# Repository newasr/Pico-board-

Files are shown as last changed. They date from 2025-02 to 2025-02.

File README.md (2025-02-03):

# Pico Board Replica

## Overview
This project is a replica of the Raspberry Pi Pico board, designed from scratch as a learning and practice exercise.

## Features
- Based on the RP2040 microcontroller
- Same form factor and pinout as the original Raspberry Pi Pico
- Designed using Kicad
- Fully open-source hardware

## Design Files
- **Schematics:**  
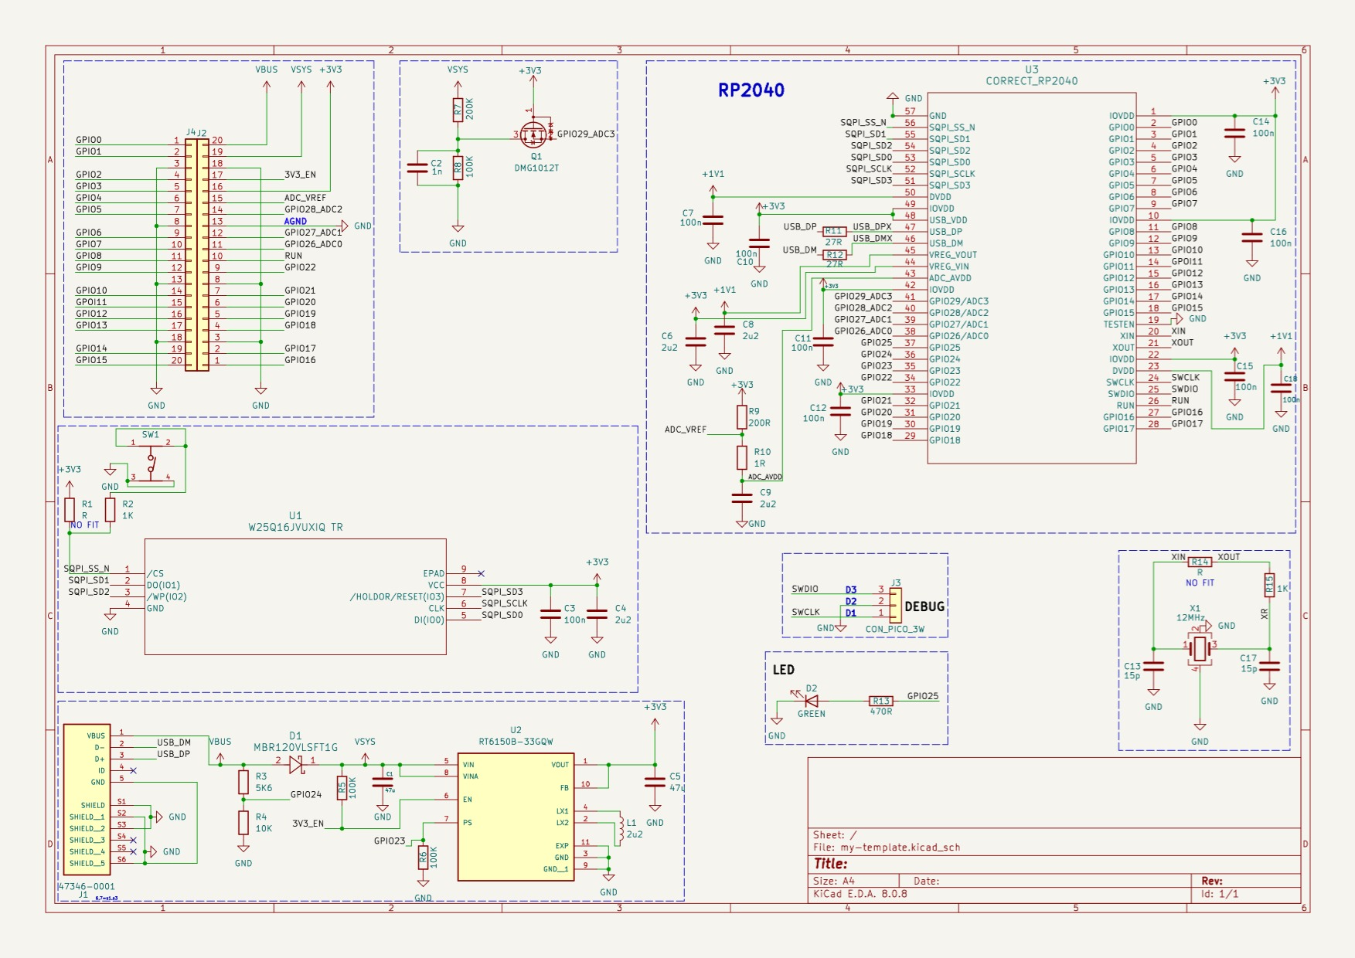
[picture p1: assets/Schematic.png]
Schematic
  
- **Final Product (3D View):**  
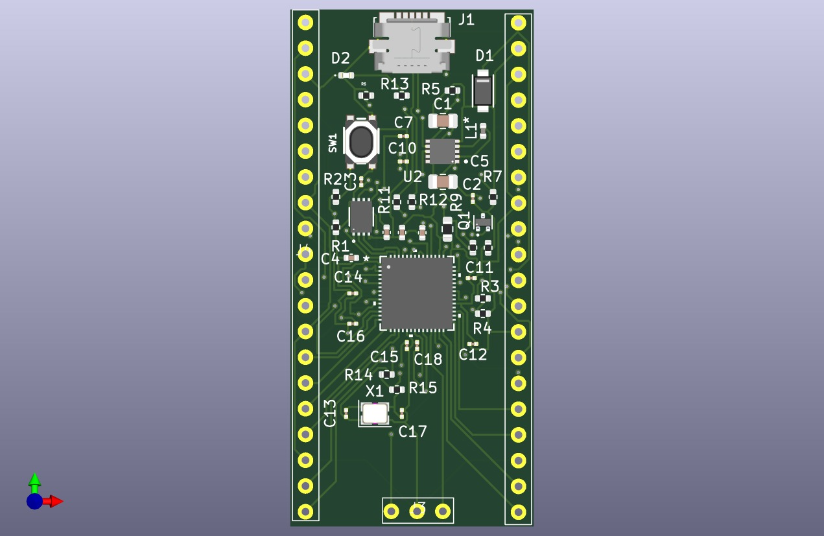
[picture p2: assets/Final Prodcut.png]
Final Product
  
- **BOM (Bill of Materials):** [Link to BOM](https://github.com/newasr/Pico-board-/tree/main/bom)
- **3D View:** [Link](https://github.com/newasr/Pico-board-/blob/main/assets/my-template.stl)

## Contributing
Feel free to open issues or submit pull requests to improve this project.

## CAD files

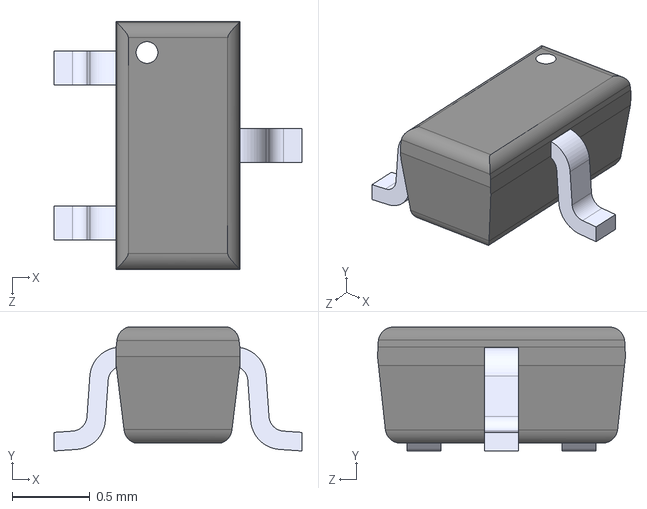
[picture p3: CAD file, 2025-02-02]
3dmodels/DMG1012T.STEP
1.60 x 0.8 x 1.60 mm

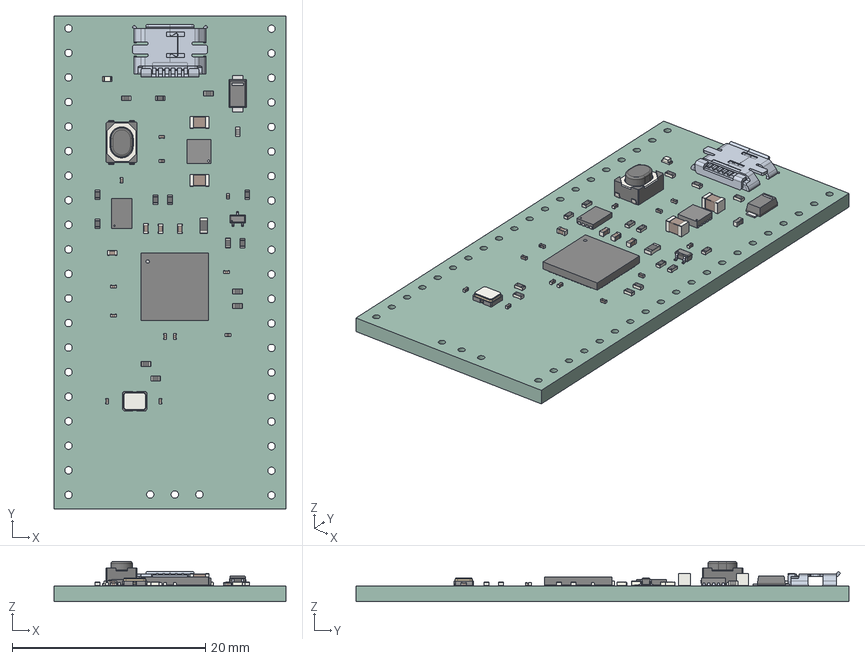
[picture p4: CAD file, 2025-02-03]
assets/my-template.step
24.0 x 51.0 x 4.15 mm
L_0402_1005Metric
R_0402_1005Metric x 14
R_0603_1608Metric
RT6150B-33GQW
C_0201_0603Metric x 12
C_0402_1005Metric x 4
2DA1774Q-7-F
C_0805_2012Metric x 2
434133025816 v4
Oscillator_SMD_SeikoEpson_SG210-4Pin_2.5x2.0mm
LED_0402_1005Metric
my-template_PCB

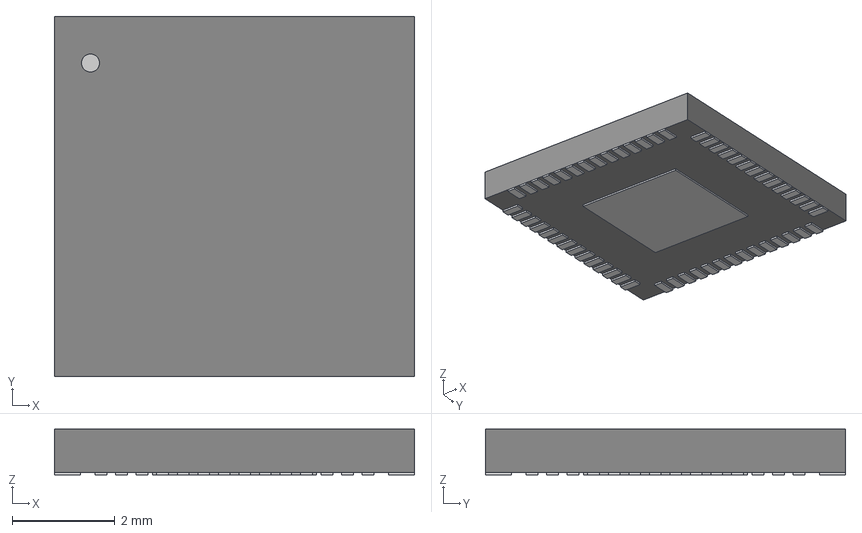
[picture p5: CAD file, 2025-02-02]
3dmodels/RP2040.step
7.01 x 7.01 x 0.892 mm

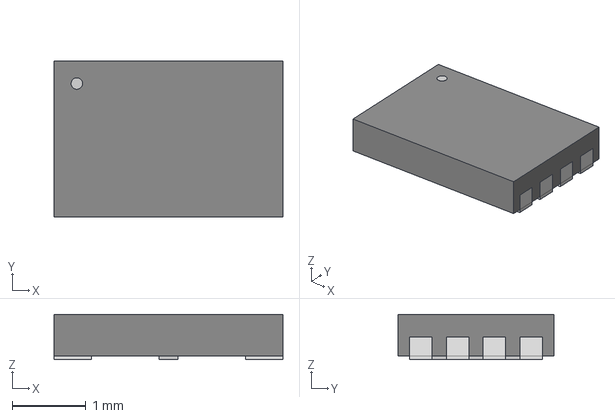
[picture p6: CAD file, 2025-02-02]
3dmodels/W25Q16JVUXIQ_TR.step
3.10 x 2.11 x 0.612 mm

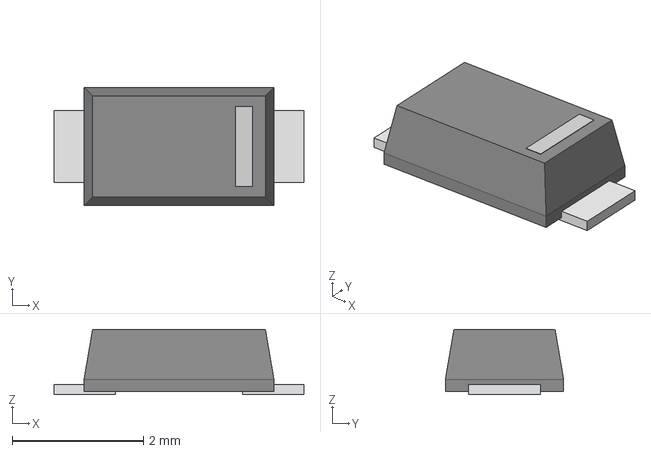
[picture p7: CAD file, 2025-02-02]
3dmodels/MBR120VLSFT1G.step
3.81 x 1.80 x 0.997 mm

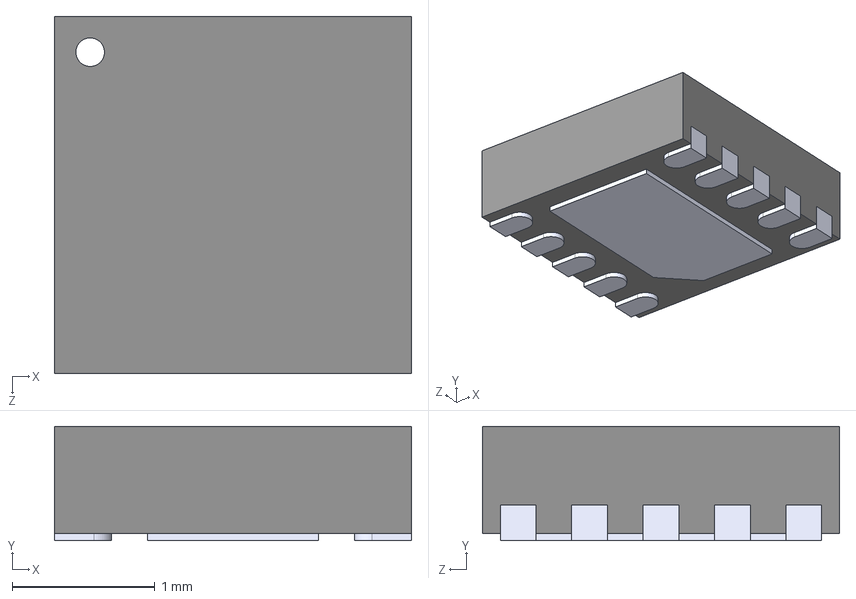
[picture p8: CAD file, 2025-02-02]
3dmodels/RT6150B-33GQW.step
2.50 x 0.8 x 2.50 mm

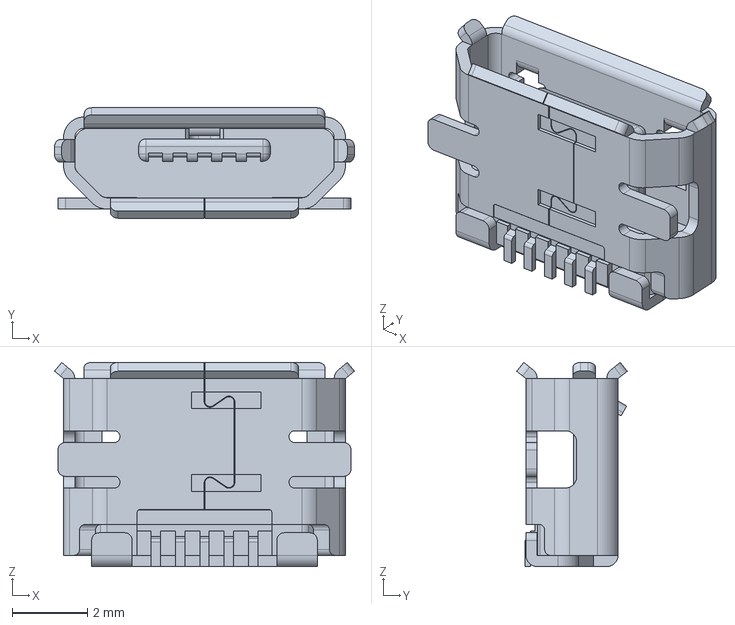
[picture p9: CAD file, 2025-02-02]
3dmodels/47346-0001.step
7.98 x 2.94 x 5.43 mm

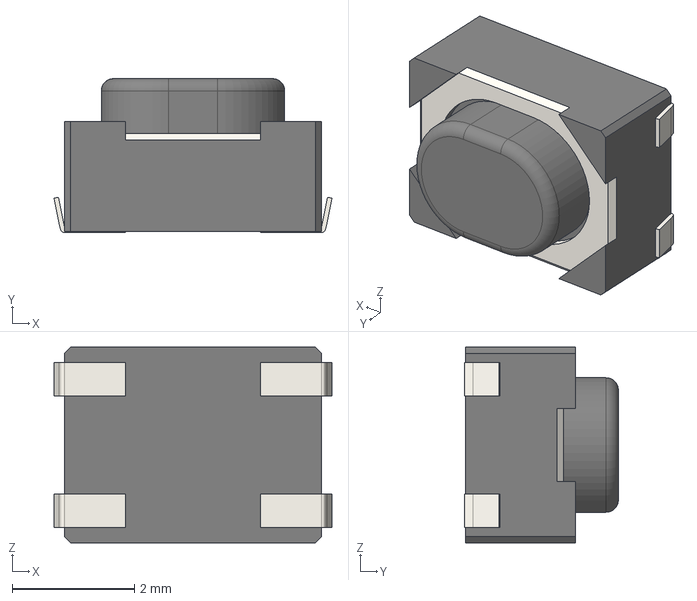
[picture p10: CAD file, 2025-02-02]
3dmodels/434133025816.step
4.55 x 2.52 x 3.20 mm

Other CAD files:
3dmodels/473460001.iges
assets/my-template.stl

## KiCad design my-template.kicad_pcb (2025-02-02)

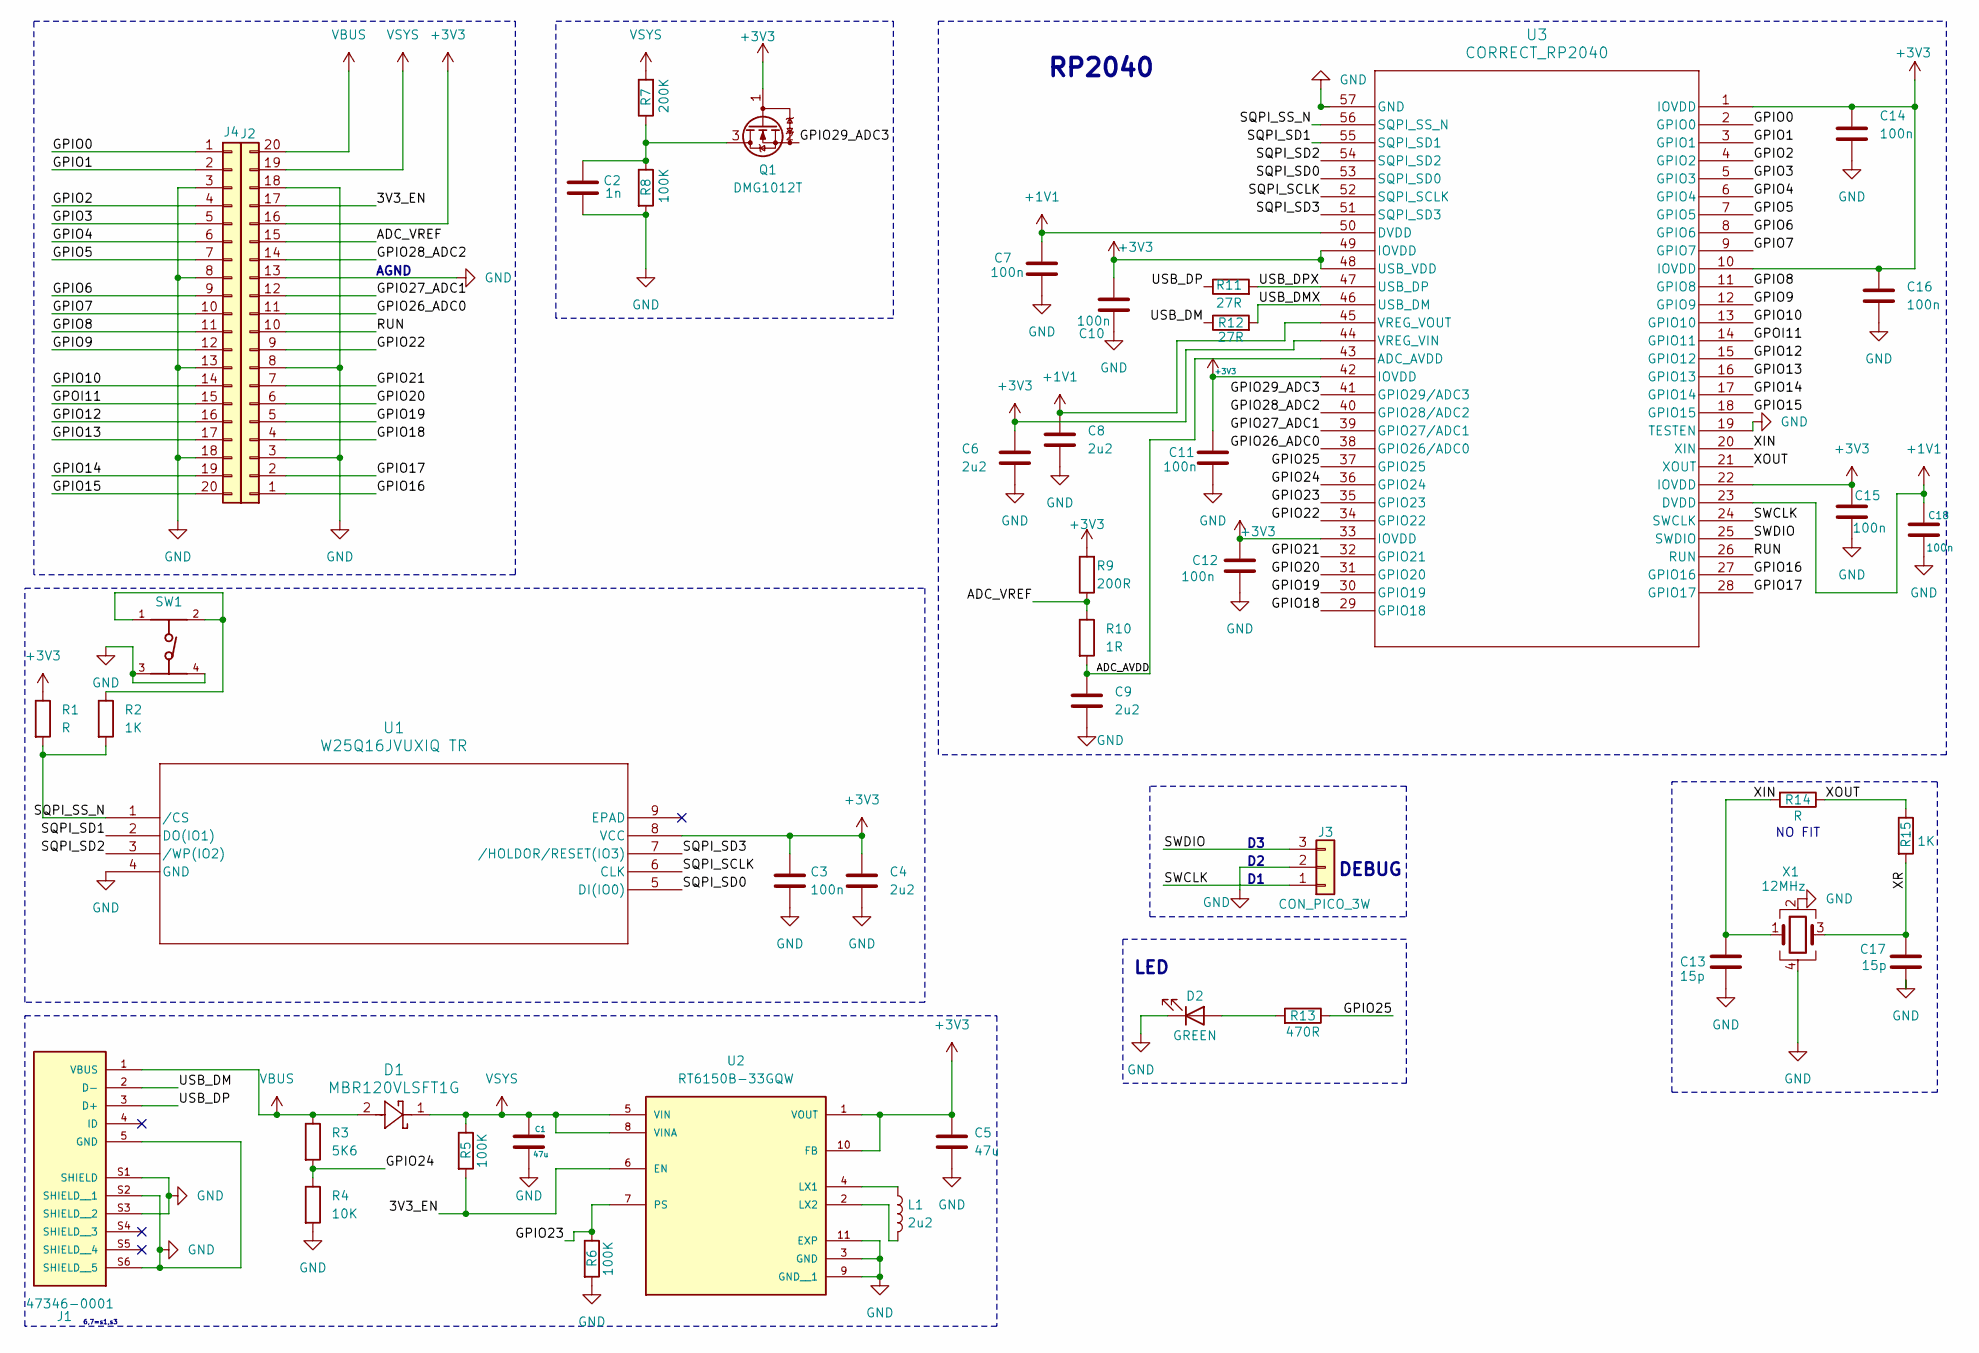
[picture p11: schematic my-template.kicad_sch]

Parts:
C1, C5: 47u; C_0805_2012Metric; Digikey Part# TACR476M006XTA
C2: 1n; C_0201_0603Metric; Digikey Part# GRM033R71E102KA01D
C3, C7, C10, C11, C12, C14, C15, C16, C18: 100n; C_0201_0603Metric; Digikey Part# 0201W104K100LE
C4, C6, C8, C9: 2u2; C_0402_1005Metric; Digikey Part# 0402W225K100HI
C13, C17: 15p; C_0201_0603Metric; Digikey Part# GRM0335C1E150JA01D
D1: MBR120VLSFT1G; Digikey Part# MBR120VLSFT1G
D2: GREEN; LED_0402_1005Metric; Digikey Part# 150040GS73240
J1: 47346-0001; MOLEX_47346-0001; PARTREV E; Digikey Part# 0473460001
J2: Conn_01x20; part_2_40_pin
J3: CON_PICO_3W; 3_pin_connector
J4: Conn_01x20; part_1_40_pin
L1: 2u2; L_0402_1005Metric; Digikey Part# MLZ1005M2R2WT000
Q1: DMG1012T; SOT-523
R1, R14: R; R_0402_1005Metric
R2, R15: 1K; R_0402_1005Metric; Digikey Part# RC0402JR-071KL
R3: 5K6; R_0402_1005Metric; Digikey Part# RC0402FR-075K6L
R4: 10K; R_0402_1005Metric; Digikey Part# RC1005F103CS
R5, R6, R8: 100K; R_0402_1005Metric; Digikey Part# RC0402FR-07100KL
R7: 200K; R_0402_1005Metric; Digikey Part# RC0402JR-103K3L
R9: 200R; R_0603_1608Metric; Digikey Part# ERJ-2RKF2000X
R10: 1R; R_0402_1005Metric; Digikey Part# CRGCQ0402J1R0
R11, R12: 27R; R_0402_1005Metric; Digikey Part# CPF0402B27RE1
R13: 470R; R_0402_1005Metric; Digikey Part# CRG0402J470R
SW1: 434133025816; PART-NUMBER 434133025816; Digikey Part# 434133025816
U1: W25Q16JVUXIQ TR; W25Q16JVUXIQ; Digikey Part# W25Q16JVUXIQ TR
U2: RT6150B-33GQW; PARTREV July 2018; Digikey Part# RT6150B-33GQW
U3: CORRECT_RP2040; Digikey Part# SC0914(7)
X1: 12MHz; Oscillator_SMD_SeikoEpson_SG210-4Pin_2.5x2.0mm; Digikey Part# ECS-2520MVLC-120-CN-TR

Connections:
+1V1: C7.1, C8.1, C18.1, U3.23 (DVDD), U3.45 (VREG_VOUT), U3.50 (DVDD)
+3V3: C3.1, C4.1, C5.1, C6.1, C10.1, C11.1, C12.1, C14.1, C15.1, C16.1, J2.16, Q1.1 (G), R1.1, R9.2, U1.8 (VCC), U2.1 (VOUT), U2.10 (FB), U3.1 (IOVDD), U3.10 (IOVDD), U3.22 (IOVDD), U3.33 (IOVDD), U3.42 (IOVDD), U3.44 (VREG_VIN), U3.48 (USB_VDD), U3.49 (IOVDD)
/3V3_EN: J2.17, R5.2, U2.6 (EN)
/ADC_AVDD: C9.1, R10.2, U3.43 (ADC_AVDD)
/ADC_VREF: J2.15, R9.1, R10.1
/GPIO0: J4.1, U3.2 (GPIO0)
/GPIO1: J4.2, U3.3 (GPIO1)
/GPIO2: J4.4, U3.4 (GPIO2)
/GPIO3: J4.5, U3.5 (GPIO3)
/GPIO4: J4.6, U3.6 (GPIO4)
/GPIO5: J4.7, U3.7 (GPIO5)
/GPIO6: J4.9, U3.8 (GPIO6)
/GPIO7: J4.10, U3.9 (GPIO7)
/GPIO8: J4.11, U3.11 (GPIO8)
/GPIO9: J4.12, U3.12 (GPIO9)
/GPIO10: J4.14, U3.13 (GPIO10)
/GPIO12: J4.16, U3.15 (GPIO12)
/GPIO13: J4.17, U3.16 (GPIO13)
/GPIO14: J4.19, U3.17 (GPIO14)
/GPIO15: J4.20, U3.18 (GPIO15)
/GPIO16: J2.1, U3.27 (GPIO16)
/GPIO17: J2.2, U3.28 (GPIO17)
/GPIO18: J2.4, U3.29 (GPIO18)
/GPIO19: J2.5, U3.30 (GPIO19)
/GPIO20: J2.6, U3.31 (GPIO20)
/GPIO21: J2.7, U3.32 (GPIO21)
/GPIO22: J2.9, U3.34 (GPIO22)
/GPIO23: R6.1, U2.7 (PS), U3.35 (GPIO23)
/GPIO24: R3.2, R4.1, U3.36 (GPIO24)
/GPIO25: R13.1, U3.37 (GPIO25)
/GPIO26_ADC0: J2.11, U3.38 (GPIO26/ADC0)
/GPIO27_ADC1: J2.12, U3.39 (GPIO27/ADC1)
/GPIO28_ADC2: J2.14, U3.40 (GPIO28/ADC2)
/GPIO29_ADC3: Q1.2 (S), U3.41 (GPIO29/ADC3)
/GPOI11: J4.15, U3.14 (GPIO11)
/RUN: J2.10, U3.26 (RUN)
/SQPI_SCLK: U1.6 (CLK), U3.52 (SQPI_SCLK)
/SQPI_SD0: U1.5 (DI(IO0)), U3.53 (SQPI_SD0)
/SQPI_SD1: U1.2 (DO(IO1)), U3.55 (SQPI_SD1)
/SQPI_SD2: U1.3 (/WP(IO2)), U3.54 (SQPI_SD2)
/SQPI_SD3: U1.7 (/HOLDOR/RESET(IO3)), U3.51 (SQPI_SD3)
/SQPI_SS_N: R1.2, R2.2, U1.1 (/CS), U3.56 (SQPI_SS_N)
/SWCLK: J3.1, U3.24 (SWCLK)
/SWDIO: J3.3, U3.25 (SWDIO)
/USB_DM: J1.2 (D-), R12.1
/USB_DMX: R12.2, U3.46 (USB_DM)
/USB_DP: J1.3 (D+), R11.1
/USB_DPX: R11.2, U3.47 (USB_DP)
/XIN: C13.1, R14.2, U3.20 (XIN), X1.1
/XOUT: R14.1, R15.1, U3.21 (XOUT)
/XR: C17.1, R15.2, X1.3
GND: C1.2, C2.2, C3.2, C4.2, C5.2, C6.2, C7.2, C8.2, C9.2, C10.2, C11.2, C12.2, C13.2, C14.2, C15.2, C16.2, C17.2, C18.2, D2.1 (K), J1.5 (GND), J1.S1 (SHIELD), J1.S2 (SHIELD__1), J1.S3 (SHIELD__2), J1.S6 (SHIELD__5), J2.3, J2.8, J2.13, J2.18, J3.2, J4.3, J4.8, J4.13, J4.18, R4.2, R6.2, R8.2, SW1.3, SW1.4, U1.4 (GND), U2.3 (GND), U2.9 (GND__1), U2.11 (EXP), U3.19 (TESTEN), U3.57 (GND), X1.2, X1.4
unnamed: D2.2 (A), R13.2
unnamed: C2.1, Q1.3 (D), R7.1, R8.1
unnamed: R2.1, SW1.1, SW1.2
unnamed: L1.1, U2.4 (LX1)
unnamed: L1.2, U2.2 (LX2)
VBUS: D1.2, J1.1 (VBUS), J2.20, R3.1
VSYS: C1.1, D1.1, J2.19, R5.1, R7.2, U2.5 (VIN), U2.8 (VINA)

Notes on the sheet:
DEBUG
NO FIT
AGND
6,7=s1,s3
RP2040
LED

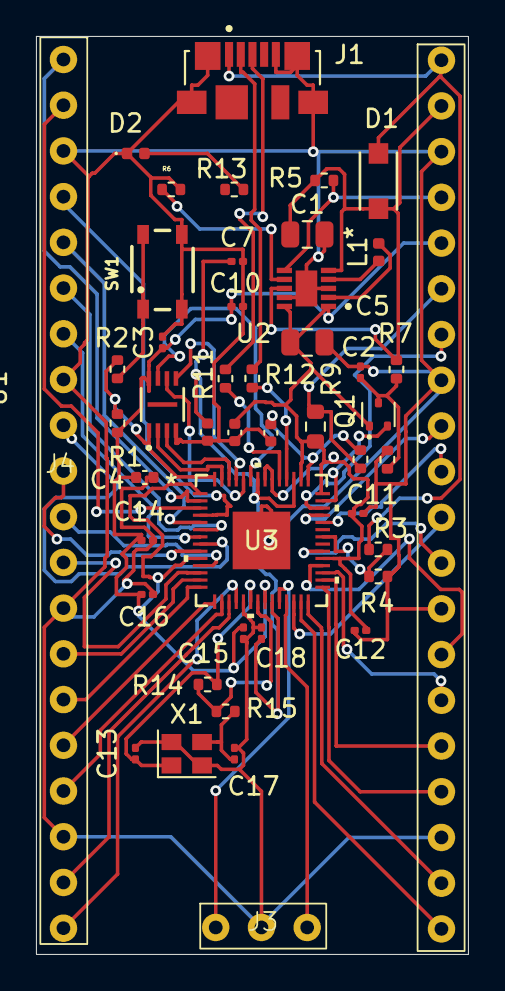
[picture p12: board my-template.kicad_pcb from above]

Board: 2 copper layers, 24.0 x 51.0 mm, 46 parts (0 on the bottom side), 59 nets.

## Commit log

2025-02-02 added 3d files
    [434133025816.step, 47346-0001.step, 473460001.iges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]
2025-02-02 gerber go brrr
    [my-template-B_Cu.gbr, my-template-B_Mask.gbr, my-template-B_Paste.gbp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]
2025-02-02 added remaining files
    [my-template.kicad_pcb, my-template.kicad_sch]
2025-02-03 added assets
    circuit, final prodcut, 3d view step file
    [my-template.step]
